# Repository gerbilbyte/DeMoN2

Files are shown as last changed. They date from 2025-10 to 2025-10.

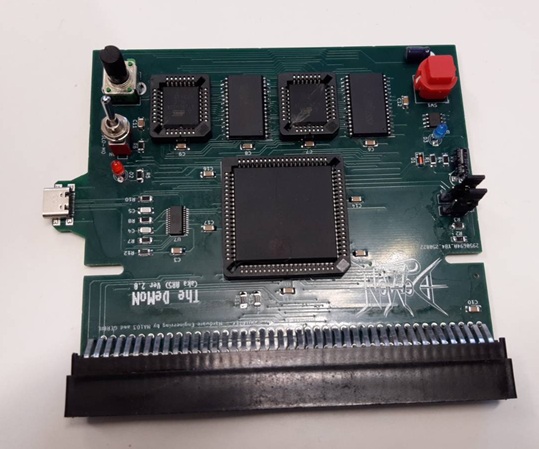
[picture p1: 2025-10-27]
Images/DeMoN_2.0_PLCC.jpeg

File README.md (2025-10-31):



# DeMoN II

The DeMoN II is hobby cartridge that was developed as a collaboration between three geeks who have a very healthy obsession with the Amiga, and skilled in both software and hardware development alike. It can be described as an Action Replay on steroids.
It is the successor of the original DeMoN cartridge that can be found [here](https://github.com/gerbilbyte/DeMoN/).



This project will give a brief introduction, how it came to be, its features and plans so that you can build your own.

## Contents

[A Brief History](https://github.com/gerbilbyte/DeMoN2/blob/main/README.md#a-brief-history) (the boring bit. In fact, skip over this bit).

[DeMoN II features](https://github.com/gerbilbyte/DeMoN2/blob/main/README.md#features)

[Compatibility](https://github.com/gerbilbyte/DeMoN2/blob/main/README.md#compatibility)

[DeMoN II User Manual](https://github.com/gerbilbyte/DeMoN2/blob/main/README.md#demon-ii-user-manual)

[Build Your Own](https://github.com/gerbilbyte/DeMoN2/blob/main/README.md#build-your-own-demon-ii-cartridge)

* [Firmware](https://github.com/gerbilbyte/DeMoN2/blob/main/README.md#firmware)
  * [CLPD](https://github.com/gerbilbyte/DeMoN2/blob/main/README.md#clpd)
  * [DeMoN II](https://github.com/gerbilbyte/DeMoN2/blob/main/README.md#demon-ii-rom)
* [Flashing](https://github.com/gerbilbyte/DeMoN2/blob/main/README.md#flashing) 
* [Cartridge Case](https://github.com/gerbilbyte/DeMoN2/blob/main/README.md#cartridge-case)
* [License](https://github.com/gerbilbyte/DeMoN2/blob/main/README.md#license)
   
[Related Projects](https://github.com/gerbilbyte/DeMoN2/blob/main/README.md#related-projects)

## A Brief History - Part Two

For a brief history on the DeMoN cart please see the '[Brief History](https://github.com/gerbilbyte/DeMoN/blob/main/README.md#a-brief-history)' blurb on the original DeMoN cart repo.

Since the release of the original DeMoN, a few changes were made which made the cartridge a more superior piece of kit.
Firstly, the idea of adding a USB port to allow serial transfer of data came into fruition. This was planned and the idea became a reality.
No longer does an Amiga user need to use fiddly serial ports to talk between their Amiga and their PC.
Secondly, the five GALs were replaced by a single CLPD. This allowed for better features involving more complex PCB layouts.

The majority, if fact ALL of the work done on this version can be creditted to [na103](https://github.com/na103) and [REbEL](https://github.com/dmcoles) as they did all the work. Excellent work guys! 

## Features

So what is so special about the DeMoN II cartridge, and how does it compare against an original Action Replay 3 and the original DeMoN cartridge?
In a nutshell:

| FEATURE | Action Replay 3 | DeMoN Cartridge | DeMoN II Cartridge
|---|---|---|---|
| ROM size | 256kb | 256kb | 256kb |
| ROM type | Static | Flashable | Flashable |
| RAM size | 40kb | 1mb | 1mb |
| Number of Tools | Loads | Even more! | MORE!!! |
| Ramdisk? | No | Optional | Optional |
| Detection | Always hidden | Can be visible | Can be visible |
| Ability toggle? | Always On | Optional | Optional |
| USB-C port | No | No | Yes |
| Amiga <--> PC File Transfer Ability? | No | Yes | Yes |

Other features of the DeMoN II cartridge:

* **Backwards Compatibility** - The DeMoN firmware has also been designed to work with the original Action Replay 3 hardware and it is also supported in WinUAE. 
* **DeMoN Detection** - The user has the option whether the DeMoN can be "seen" by the Amiga, peripherals etc. **IMPORTANT! Don't toggle this jumper whilst powered on!**
* **DeMoN Ability** - DeMoN has the option to be "On" or "Off". **IMPORTANT! Don't toggle this jumper whilst powered on!**
* **Keyboard Layouts** - New keyboard layouts to cater for the United Kingdom and Italian language have been added. 
* **Serial Communication** - The DeMoN allows serial communications, but this is currently a Work In Progress. Tests have successfully sent and received files between Amiga and PC. 
* **Extra Tools** - The DeMoN cartridge contains all the commands from the Action Replay 3 cartridge and the Aktion Replay 4 software. Further to this, several bugs have been fixed. Too many to list here, but a few DeMoN specific commands that have been added are:
  * flash: Used to upgrade firmware.
  * r: This is the ramdisk. It can be accessed using R: as the drive in any of the file tools within the DeMoN console.
  * savecfg: Save your current config to the cartridge.
  * resetcfg: Set config to default.
  * axfer: Sets up the Amiga to use AmigaXfer without the need of a floppy.
  * rfy, sfy: Send and receive files via Y-Modem (currently a Work In Progress). 
  * ...plus many, many more!
  #tk#

See the [manual](https://github.com/dmcoles/ActionReplay5/blob/main/Action%20Replay%205%20Manual.pdf) for a full list of commands available.

## Compatibility

DeMoN II cart is only compatible with A500 and A500+ computers.

Tested and works with chipsets:
 * 68010
 * TF536 (68030)

It has been tested on the following kickstarts:
 * 1.3
 * 2.04
 * 2.05
 * 3.0
 * 3.1
 * 3.x
 * 3.1.4
 * 3.2.x

It is also compatible with any memory expansions and disk controllers.

Tested and works with:
 * 8MB GottaGoFastRam
 * GVP Impact A2000-HC+8 Series II

We are currently working on expanding this, so watch this space!

## DeMoN II User Manual

A user manual for the DeMoN/Action Replay 5 has been written and can be found on REbEL's [Action Replay 5](https://github.com/dmcoles/ActionReplay5) repo.
A direct link to the manual can be found [here](https://github.com/dmcoles/ActionReplay5/blob/main/Action%20Replay%205%20Manual.pdf).

## Build Your Own DeMoN II Cartridge

If you want to build your own then you will need the following:
* Soldering Iron
* Solder
* Tweezers
* ESD wrist strap
* A flat surface to solder on (such as a soldering mat on a desk, NOT the arm of a sofa or your partner's back)
* Other soldering related tools and devices, you know the drill.

In this project you can find the KiCad files that are used to build the PCBs for the project, along with the [Bill of Materials](https://github.com/gerbilbyte/DeMoN2/tree/main/Kicad) (BOM) required for each build.
To make things even easier, Gerber files have also been included that you can use to send directly to your favourite freindly, or unfriendly, PCB manufacturer.



Follow this link to build the [DeMoN II](https://github.com/gerbilbyte/DeMoN2/tree/main/Kicad/DeMoN_2.0_PLCC)

I actually don't need to write any more about how to build one, the rest is quite straight forward.

### Firmware.

Once built, your cartridge will now need firmware.

#### CLPD
The CLPD will also need to be programmed, and this can be done using a seperate programmer such as an ATF Programmer (Details of the AFT that we used can be found at the bottom of this repo).
The CLPD can be programmed with the [DeMoN.jed](https://github.com/gerbilbyte/DeMoN2/blob/main/Quartus/output_files/DeMoN.jed) file that can be found in the folder [here](https://github.com/gerbilbyte/DeMoN2/blob/main/Quartus/output_files).

#### DeMoN II ROM
This repo does not contain firmware, but it does contain a patch file that can be used to patch the original Action Replay III (version 3.17) ROM.
Tools are included with instructions in this repo on how to patch an Action Replay III ROM file.

Due to changes in hardware, the DeMoN II firmware will not work with the original DeMoN or Action Replay 3/5 cart. From versions 5.2.0 onwards, DeMoN II firmware will be packaged in the same release archive as the Action Replay 5 firmware found on REbEL's GitHub repo which can be found [here](https://github.com/dmcoles/ActionReplay5).

### Flashing.

#### **Flashing using a chip programmer**

All tools required for flashing can be found in the FirmwareTools folder of this repo.
To prepare the firmware for the flash chips the following steps can be taken:
* Prepare the firmware by using the patchfile and the AR3 image to obtain the firmware:

   ```python3 DeMoNpatcher.py <AR3rom file> <DeMoNpatch file>```

* Split the file to be used for programming the chips. The obtained files are self descriptive:

   ```python3 firmwareSplitter.py <input_file>```

* Power-cycle the Amiga.
And that's it! Enjoy the cartridge! :)

#### **Flashing using the stand-alone flash tool**

All tools required for stand-alone flashing - along with detailed instruction on how to use it - can be found in the Standalone Flash Tool folder of this repo.
But in a nutshell, the process is as follows:
* Set JP1 on the DeMoN to pins 2-3 to make the DeMoN memory visible to the Amiga.
* Set JP2 on the DeMoN to pins 2-3 to functionally deactivate the DeMoN.
* Prepare an Amiga floppy disk that includes a standard bootblock (without starup-sequence), the ar5flasher tool and also the firmware
* Load disk and enter the following command, following any futher on screen instructions:

   ```ar5flasher firmware.rom```

* Power-cycle the Amiga.
And that's it! Enjoy the cartridge! :)

#### **Flashing using the FLASH tool on DeMoN**
All that is needed for this method is the firmware on a floppy disk.
* Set JP1 on the DeMoN to pins 2-3 to make the DeMoN memory visible to the Amiga.
* Copy the firmware onto a floppy, and insert it into the drive.
* Press DeMoN freeze button.
* At the console type in the following command, following any futher on screen instructions:

   ```flash firmware.rom```

   The flashing and verifying will take place. After verifying, the screen will change colour to match one of the following conditions:
  
   Red = Failed flash. An error has happened causing the checksums of the firmware file and the on-board firmware to differ.

   Green = Successful flash!
* Power-cycle the Amiga.
And that's it! Enjoy the cartridge! :)

### Cartridge Case.
The case:

![image](https://github.com/user-attachments/assets/d45c8bf2-c362-421a-aed6-7b5a509b44b4)

A case dedicated to DeMoN has been created and can be found [here](https://www.printables.com/model/1307217-amiga-demon-action-replay-5-case). STEP and STL files for this can be found in this repo [here](https://github.com/gerbilbyte/DeMoN/tree/main/3Dcase).

### License

This work is licensed under a Creative Commons Attribution 4.0 International License. See [https://creativecommons.org/licenses/by/4.0/](https://creativecommons.org/licenses/by/4.0/).

## Related Projects.

**REbEL**, the author of the DeMoN firmware has an open project (Action Replay 5) that can be found [here](https://github.com/dmcoles/ActionReplay5). This repo contains firmware that can be used in WinUAE as well as DeMoN. These will be up-to-date and more stable, including source code. His main github page can be found [here](https://github.com/dmcoles).

**na103**, who reverse engineered the Action Replay 3, has posted his project here. This repo contains several versions of the Action Replay 3 for different ROM footprints. His main github page can be found [here](https://github.com/na103).

**Fongo**, the creator of the Action Replay Replica and DeMoN Cases. His Printables page can be found [here](https://www.printables.com/@fongo2k_2502418).

The ATF150x programmer needed to program the CPLD can be found [here](https://github.com/roscopeco/atfprog-hardware).

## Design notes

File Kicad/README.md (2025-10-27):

## Bill of materials
| Qt. | Description | Designator | Mouser part | Note |
|:---:|---|---|---|---|
|6 |Resistor 1K |R4-R6, R9, R11, R13 |CRCW12061K00FKEA | |
|1 |Resistor 4.7K |R1 |CRCW12064K70FKEA | |
|2 |Resistor 220R |R2, R3 |CRCW1206220RFKEA | |
|2 |Resistor 27R |R7, R8 |CRCW120627R0FKEA | |
|2 |Resistor 5.1K |R10, R12 |CRCW12065K10FKEA | |
|1 |Cap. 10uF 16V |C1 |EEA-FC1E100H | |
|13 |Cap. 100nf |C3, C6-C17 |C1206C104K5RAC7867  | |
|1 |Cap. 1uF 63V |C2 |ESS105M050AB2AA | |
|2 |Cap. 47 pf |C4, C5 |C1206C470J5RACTU | |
|1 |CPLD PLCC 84 |U1 |ATF1508AS-15JC84 | | 
|1 |PLCC 84 POS Socket  |U1 |8484-21B1-RK-TP | |
|2 |AT29C010A PEROM |U3, U5 |AT29C010A-70JC | |
|2 |PLCC 32 POS Socket  |U3, U5 |8432-21B1-RK-TR | Optional |
|2 |SRAM 4Mb |U4, U6 |IS61C5128AS-25QLI | |
|1 |MC1455 |U2 |MC1455DR2G | |
|1 |FT240 |U7 |FT240XS-R | |
|1 |Trimmer 10K |VR1 |RV09AF-40-20K-B10K  | |
|1 |Red LED |D2 |TLCS5100 | |
|1 |Green LED |D3 |TLCYG5100 | |
|1 |Diode |D1 |LL4148-M-18 | |
|1 |Button switch red |SW1 |D6C40F1LFS | |
|1 |SPDT ON-ON switch |SW2 |2MS1T1B3M2QES | |
|1 |Conn edge female 86p|CN1 |ECC43DCAI-S189 | from ebay or digikey ECC43DCAI-S189 |
|1 |USB C Rec 16P |J1 |USB4110-GF-A | |
|2 |Pin strip 1x3 male  |JP1  JP2 |G800LR305018EU | |

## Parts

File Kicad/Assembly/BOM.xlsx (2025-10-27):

Comment | Designator | Footprint | JLCPCB Part #（optional）
FT240XS | U7 | SSOP-24-150mil | C2651872
SMD USB Connectors | J1 | USB4110-GF-A | C5143397

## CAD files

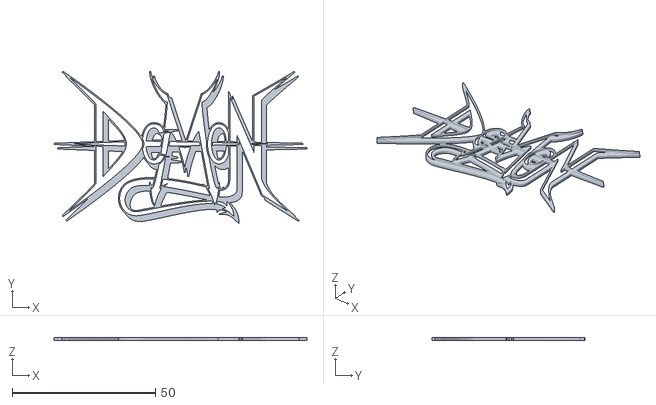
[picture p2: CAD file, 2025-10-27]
3DCase/DeMoN_Case_Top_Logo_Black.stl
88.2 x 53.1 x 1.00

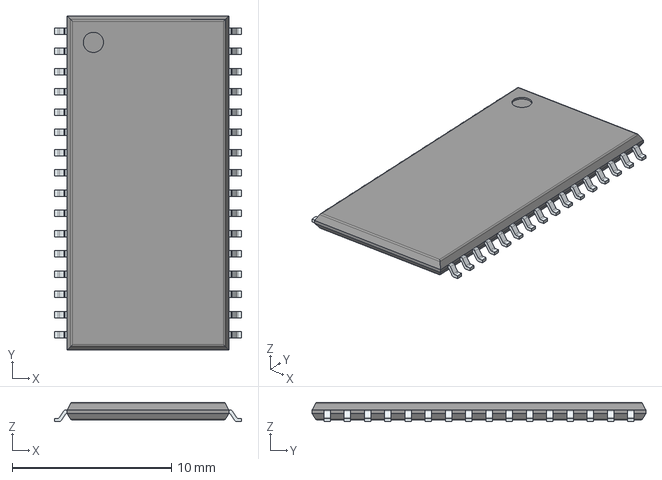
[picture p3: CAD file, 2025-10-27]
Kicad/DeMoN_2.0_PLCC/3D/IS61C5128AS-25TLI.stp
11.8 x 20.9 x 1.20 mm
PinsArrayLR

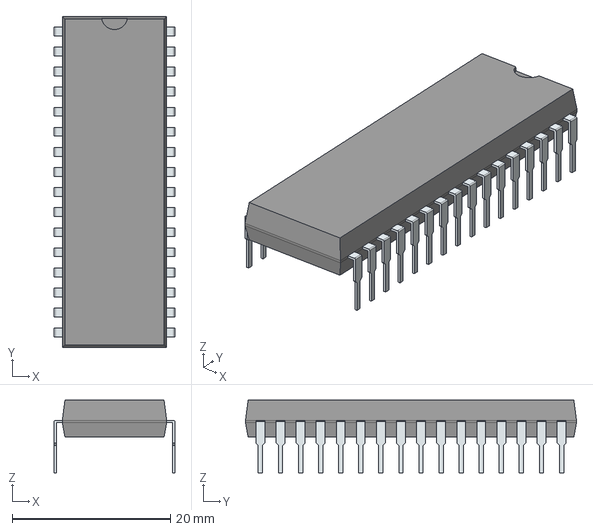
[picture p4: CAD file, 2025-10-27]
Kicad/DeMoN_2.0_PLCC/M27C1001-12F1/M27C1001-12F1.stp
15.3 x 41.9 x 9.22 mm
PinsArrayLR

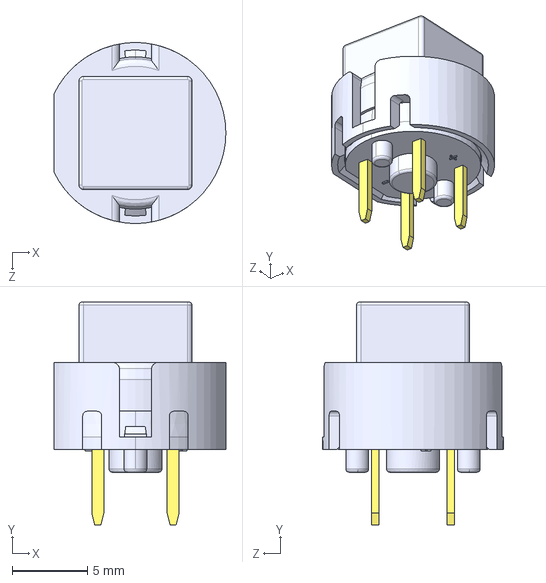
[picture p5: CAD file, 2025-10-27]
Kicad/DeMoN_2.0_PLCC/RV09AF-40-20K/D6C40F2LFS.stp
11.4 x 14.8 x 12.0 mm

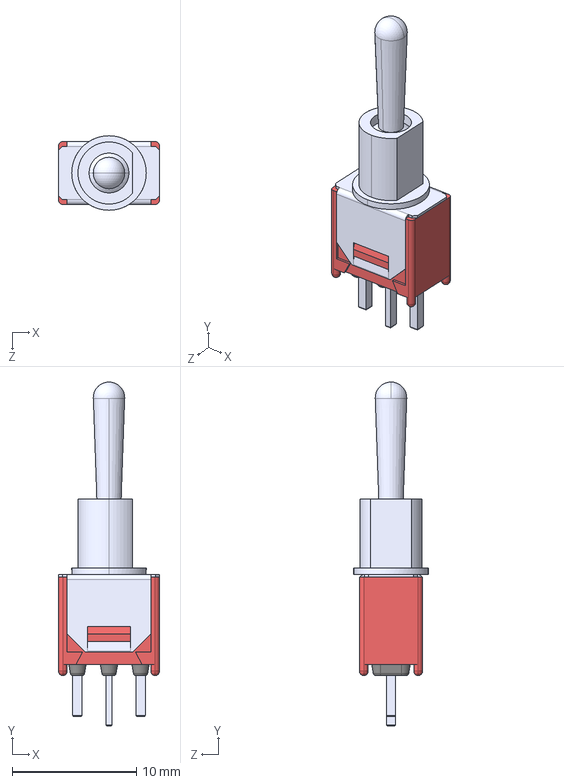
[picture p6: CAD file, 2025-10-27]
Kicad/DeMoN_2.0_PLCC/USB4110-GF-A/2MS1T1B1M2QES.stp
8.13 x 27.7 x 6.00 mm

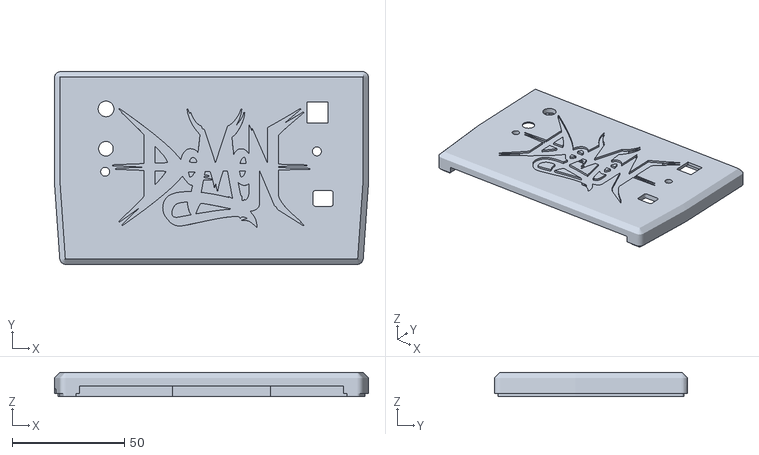
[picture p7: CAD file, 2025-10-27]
3DCase/DeMoN_Case_Top_Logo_Gray.stl
140.0 x 86.0 x 10.9

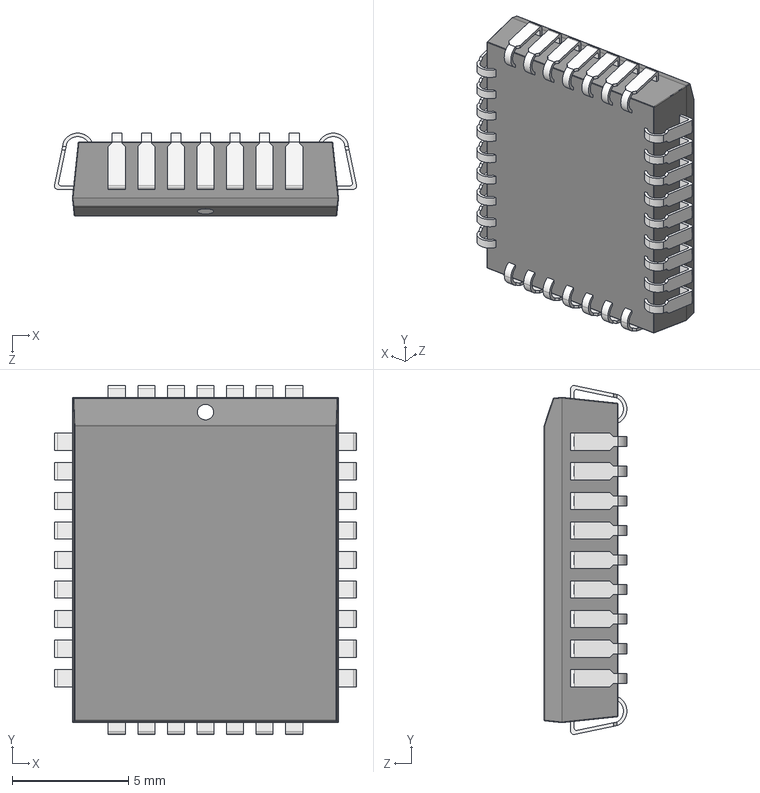
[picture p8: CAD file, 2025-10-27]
Kicad/DeMoN_2.0_PLCC/3D/AT27C256R-70JU-T.stp
13.0 x 15.0 x 3.56 mm
terminal
logo

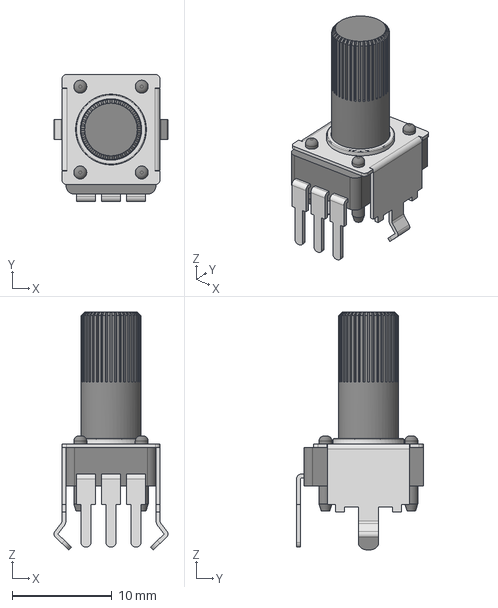
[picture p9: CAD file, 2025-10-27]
Kicad/DeMoN_2.0_PLCC/RV09AF-40-20K/RV09AF-40-20K-B10K.stp
11.4 x 12.7 x 23.8 mm

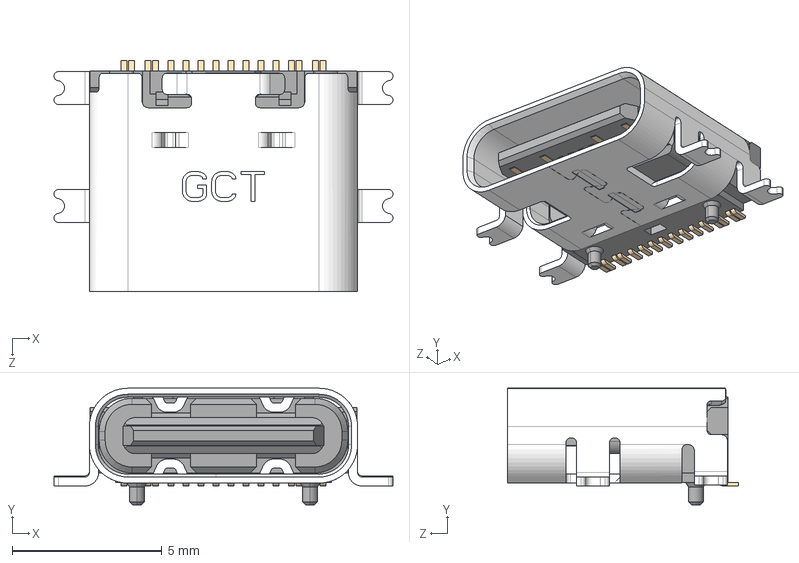
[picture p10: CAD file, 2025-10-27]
Kicad/DeMoN_2.0_PLCC/USB4110-GF-A/USB4110-GF-A.stp
11.3 x 3.89 x 7.70 mm

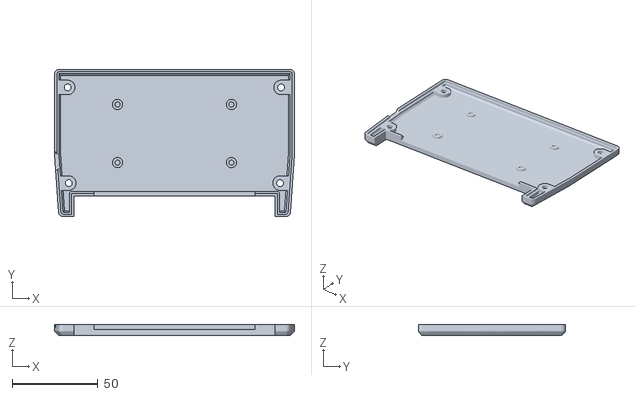
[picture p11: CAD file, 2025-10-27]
3DCase/DeMoN_Case_Bottom.stl
140.0 x 86.0 x 6.50

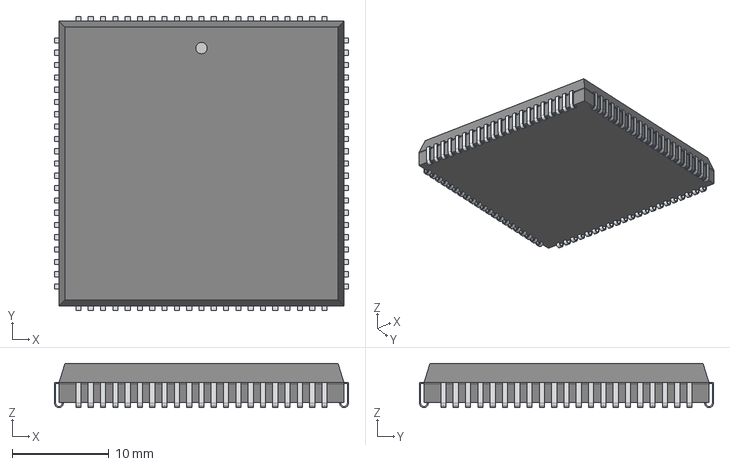
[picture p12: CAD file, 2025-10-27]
Kicad/DeMoN_2.0_PLCC/3D/PLCC84_84J_MCH.step
30.4 x 30.4 x 4.58 mm

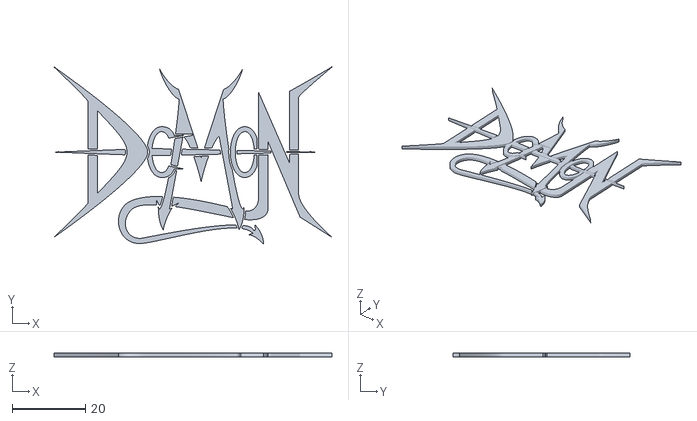
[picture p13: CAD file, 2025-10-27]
3DCase/DeMoN_Case_Top_Logo_Red.stl
76.2 x 48.5 x 1.00

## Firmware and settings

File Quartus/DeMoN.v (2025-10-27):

`timescale 1ns / 1ps

//DeMoN logic code written by REbEL and na103
//adapted from the original Action Replay MK III GAL logic equations
//version 1.0

module DeMoN(               //                     HANDLED
                            // PIN NAME    TYPE    BY      DESCRIPTION            
                            // --- -------  ------- ------- --------------------------  
  input a1,                 // 4   A1
  input a2,                 // 5   A2
  input a3,                 // 6   A3
  input a4,                 // 8   A4
  input a5,                 // 9   A5
  input a6,                 // 10  A6
  input a7,                 // 11  A7
  input a8,                 // 12  A8
  input a9,                 // 14  A9
  input a10,                // 15  A10
  input a11,                // 16  A11
  input a12,                // 17  A12
  input a13,                // 18  A13
  input a14,                // 20  A14
  input a15,                // 21  A15
  input a16,                // 22  A16
  input a17,                // 23  A17
  input a18,                // 24  A18
  input a19,                // 25  A19
  input a20,                // 81  A20
  input a21,                // 80  A21
  input a22,                // 79  A22 
  input a23,                // 77  A23
  input slomosw,            // 55  slomosw
  input sw1,                // 33  sw1
  input jp1,                // 29  jp1
  input jp2,                // 30  jp2
  input slomotick,          // 31  slomotick
  input fc0,                // 27  fc0
  input fc1,                // 28  fc1
  input lds,                // 35  lds
  input uds,                // 36  uds
  input as,                 // 37  as
  output oe,                // 39  oe
  inout reg d0,             // 40  d0
  inout reg d1,             // 41  d1
  input r_w,                // 44  r_w
  input rst,                // 45  rst
  output ipl0,              // 46  ipl0
  output ipl1,              // 48  ipl1
  output ipl2,              // 49  ipl2
  inout hlt,                // 50  hlt
  output romce1,            // 51  romce1
  output romce2,            // 52  romce2
  output ramce1,            // 54  ramce1
  output ramce2,            // 34  ramce2
  output reg nmivec,        // 56  nmivec
  output reg ovrdrive,      // 57 ovr drive
  output ovr,               // 58  ovr
  output dtack,             // 60  dtack
  output reg u3o13,         // 73  u3o13
  output reg trigger,       // 74  trigger
  output reg runningflag,   // 75  runningflag
  output reg cause0,        // 76  cause0
  output reg cause1,        // 67  cause1
  output reg bfe001triggering,  // 68  bfe001triggering
  output reg bfd100triggering,  // 69  bfd100triggering
  output iack,              // 70  iack
  output ft_wr,             // 61  ft_rw
  output ft_rd,             // 62  ft_rd
  input ft_txe,             // 63  ft_txe
  input ft_rxf,             // 64  ft_rxf
  output ft_siwu            // 65  ft_siwu
  
);

  //ciaa pra register (used to trigger DeMoN) 
  wire addrbfe001 = a23 & !a22 & a21 & a20 & a19 & a18 & a17 & a16 & a15 & a14 & a13 & !a12 & !a11 & !a10 & !a9 & !a8 & !a7 & !a6 & !a5 & !a4 & !a3 & !a2 & !a1;

  //ciab prb register (used to trigger DeMoN)
  wire addrbfd100 = a23 & !a22 & a21 & a20 & a19 & a18 & a17 & a16 & a15 & a14 & !a13 & a12 & !a11 & !a10 & !a9 & a8 & !a7 & !a6 & !a5 & !a4 & !a3 & !a2 & !a1;

  //address 8 (triggers DeMoN on reset)
  wire addr000008 = !a23 & !a22 & !a21 & !a20 & !a19 & !a18 & !a17 & !a16 & !a15 & !a14 & !a13 & !a12 & !a11 & !a10 & !a9 & !a8 & !a7 & !a6 & !a5 & !a4 & a3 & !a2 & !a1;
  
  //a80000-abffff (DeMoN ROM space)
  wire romaddr = a23 & !a22 & a21 & !a20 & a19 & !a18;
  
  //ac0000-bbffff (DeMoN RAM space)
  wire ramaddr = (a23 & !a22 & a21 & !a20 & a19 & a18) | (a23 & !a22 & a21 & a20 & !a19) | (a23 & !a22 & a21 & a20 & a19 & !a18);

  //a80000 (DeMoN hardware register)
  wire arReg = a23 & !a22 & a21 & !a20 & a19 & !a18 & !a17 & !a16 & !a15 & !a14 & !a13 & !a12 & !a11 & !a10 & !a9 & !a8 & !a7 & !a6 & !a5 & !a4 & !a3 & !a2 & !a1;

  //dff000-dff1ff (Amiga custom chips)
  wire addrdffxxx = a23 & a22 & !a21 & a20 & a19 & a18 & a17 & a16 & a15 & a14 & a13 & a12;

  //$bbfff0 (DeMoN usb serial data register)
  wire usbreg1 = a23 & !a22 & a21 & a20 & a19 & !a18 & a17 & a16 & a15 & a14 & a13 & a12 & a11 & a10 & a9 & a8 & a7 & a6 & a5 & a4 & !a3 & !a2 & !a1;

  //$bbfff2 (DeMoN usb serial status register)
  wire usbreg2 = a23 & !a22 & a21 & a20 & a19 & !a18 & a17 & a16 & a15 & a14 & a13 & a12 & a11 & a10 & a9 & a8 & a7 & a6 & a5 & a4 & !a3 & !a2 & a1;

  //$bbfff0-$bbffff (DeMoN register area, allowing for future expansion
  wire addrbbfffx = a23 & !a22 & a21 & a20 & a19 & !a18 & a17 & a16 & a15 & a14 & a13 & a12 & a11 & a10 & a9 & a8 & a7 & a6 & a5 & a4;

  
  initial nmivec = 1'b1;
  initial u3o13 = 1'b1;
  initial trigger = 1'b1;       //when it goes low it triggers the cart
  initial runningflag = 1'b1;   //indicates the cart is currently running code
                                //from the cart ROM or RAM area
  
  initial cause0 = 1'b1;        //cause0 and cause1 record the mechanism by which
  initial cause1 = 1'b1;        //the DeMoN was triggered and this value is accessed
                                //by reading the arReg hardware register
  
  initial bfe001triggering = 1'b1;    //this determines if reading from address $bfe001 causes
                                      //the cart to be triggered. This is used by breakpoints
                                      //tracing etc..
                           
  initial bfd100triggering = 1'b1;    //this determines if writing to address $bfd100 causes
                                      //the cart ot be triggered. This is used by some of the
                                      //options such as disk coding
  
  always @(*) begin
  
    
    u3o13 = (!trigger | (rst & !u3o13) | (hlt & !u3o13)) ? 1'b0 : 1'b1;
    
    
    trigger = 
            //trigger on NMI if we are not already executing code from the DeMoN ROM/RAM
            ((!sw1 & runningflag & !jp2) |

            //trigger on read of $bfee01 if it is enabled and we are not already executing code from the DeMoN ROM/RAM
            (addrbfe001 & !oe & !lds & !as & !bfe001triggering & runningflag & !jp2) |

            //trigger on write to $bfd100 if it is enabled and we are not already executing code from the DeMoN ROM/RAM
            (addrbfd100 & !uds & oe &  !as & !bfd100triggering & runningflag & !jp2) |

            //trigger on write of address 8 following a reset
            (addr000008 & u3o13 & !as & runningflag & !jp2) |
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

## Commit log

2025-10-27 add build files and update some links on the main readme
    [2MS1T1B1M2QES.stp, AT27C256R-70JU-T.stp, BOM.xlsx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]
2025-10-29 Updated silkscreens
    [DeMoN_2-B_Cu.gbr, DeMoN_2-B_Mask.gbr, DeMoN_2-B_Paste.gbr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]
2025-10-31 Fixed Gerber file
    [DeMoN_2-B_Cu.gbr, DeMoN_2-B_Mask.gbr, DeMoN_2-B_Paste.gbr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]
